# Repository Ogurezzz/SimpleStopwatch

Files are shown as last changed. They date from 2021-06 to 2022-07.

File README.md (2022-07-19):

# SimpleStopwatch
SimpleStopwatch_Fr
This is very simple stopwatch. I needed something that will count time when switch is On and reset when switch is off.
I found several solutions, but most of them are hardware worktime/switchOn counter. And you need to do some workaround to reset counter.

This SimpleStopwatch will solve my problem. It can count up to 99 hours. Uses up to 6 7-segment digits.

ToDo: 
1) (DONE) Make PCB with Atmega328, quartz, ULN2003 and indicators. With remote button/switch connection.
2) (DONE)Make 3D printed and CNC milled case for this Stopwatch. It should give me option for mounting to the panel of any device.
SimpleStopwatch_Bk

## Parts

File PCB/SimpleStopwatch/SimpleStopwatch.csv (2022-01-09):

Source: | /home/ogurezzz/Documents/Coding/GithubProjects/SimpleStopwatch/PCB/SimpleStopwatch/SimpleStopwatch.sch
Date: | Пн 02 авг 2021 20:10:25
Tool: | Eeschema 5.1.5+dfsg1-2build2
Generator: | /usr/share/kicad/plugins/bom_csv_grouped_by_value.py
Component Count: | 36
Individual Components:
Item | Qty | Reference(s) | Value | LibPart | Footprint | Datasheet | Price
 |  | C1 | 22u | Device:C_Small | Capacitor_SMD:C_1210_3225Metric_Pad1.42x2.65mm_HandSolder | https://www.chipdip.ru/product/grm32er61c226k | 23
 |  | C2 | 0.1u | Device:C_Small | Capacitor_SMD:C_0603_1608Metric_Pad1.05x0.95mm_HandSolder | https://www.chipdip.ru/product/grm188r71h104k | 10
 |  | C3 | 0.1u | Device:C_Small | Capacitor_SMD:C_0603_1608Metric_Pad1.05x0.95mm_HandSolder | https://www.chipdip.ru/product/grm188r71h104k | 10
 |  | C4 | 22p | Device:C_Small | Capacitor_SMD:C_0603_1608Metric_Pad1.05x0.95mm_HandSolder | https://www.chipdip.ru/product/grm1885c1h220j | 6
 |  | C5 | 22p | Device:C_Small | Capacitor_SMD:C_0603_1608Metric_Pad1.05x0.95mm_HandSolder | https://www.chipdip.ru/product/grm1885c1h220j | 6
 |  | C6 | 0.1u | Device:C_Small | Capacitor_SMD:C_0603_1608Metric_Pad1.05x0.95mm_HandSolder | https://www.chipdip.ru/product/grm188r71h104k | 10
 |  | C7 | 22u | Device:C_Small | Capacitor_SMD:C_1210_3225Metric_Pad1.42x2.65mm_HandSolder | https://www.chipdip.ru/product/grm32er61c226k | 23
 |  | C8 | 22u | Device:C_Small | Capacitor_SMD:C_1210_3225Metric_Pad1.42x2.65mm_HandSolder | https://www.chipdip.ru/product/grm32er61c226k | 23
 |  | C9 | 100uF | Device:CP_Small | Capacitor_SMD:CP_Elec_8x10.5 | https://www.chipdip.ru/product0/535002535 | 9
 |  | D1 | B120-E3 | Diode:B120-E3 | Diode_SMD:D_SMA_Handsoldering | https://www.chipdip.ru/product/b340a-e3-61t-2 | 15
 |  | H1 | RESET | Mechanical:MountingHole_Pad | TestPoint:TestPoint_Pad_D1.0mm | Печатная плата | 200
 |  | H2 | MOSI | Mechanical:MountingHole_Pad | TestPoint:TestPoint_Pad_D1.0mm | ~ | 0
 |  | H3 | MISO | Mechanical:MountingHole_Pad | TestPoint:TestPoint_Pad_D1.0mm | ~ | 0
 |  | H4 | SCK | Mechanical:MountingHole_Pad | TestPoint:TestPoint_Pad_D1.0mm | ~ | 0
 |  | H5 | +5V | Mechanical:MountingHole_Pad | TestPoint:TestPoint_Pad_D1.0mm | ~ | 0
 |  | H6 | GND | Mechanical:MountingHole_Pad | TestPoint:TestPoint_Pad_D1.0mm | ~ | 0
 |  | J1 | Switch | Connector:Screw_Terminal_01x02 | TerminalBlock:TerminalBlock_bornier-2_P5.08mm | https://www.chipdip.ru/product/dg308-2.54-02p-14-00ah | 42
 |  | J2 | Power | Connector:Screw_Terminal_01x02 | TerminalBlock:TerminalBlock_bornier-2_P5.08mm | https://www.chipdip.ru/product/dg308-2.54-02p-14-00ah | 42
 |  | L1 | L_Small | Device:L_Small | !MyFootprints:Inductor_CD54_Sumida | https://www.chipdip.ru/product/lqh43mn150k | 21
 |  | LED1 | 7SEG_3DIG_CC_v2 | !MyElements:7SEG_3DIG_CC_v2 | !MyFootprints:LED_7SEG_3DIG_CC_0.56 | https://www.chipdip.ru/product/bc56-12ewa | 260
 |  | LED2 | 7SEG_3DIG_CC_v2 | !MyElements:7SEG_3DIG_CC_v2 | !MyFootprints:LED_7SEG_3DIG_CC_0.56 | https://www.chipdip.ru/product/bc56-12ewa | 260
 |  | R1 | R_Small | Device:R_Small | Resistor_SMD:R_0603_1608Metric_Pad1.05x0.95mm_HandSolder | https://www.chipdip.ru/product0/9000079736 | 2
 |  | R2 | 1k | Device:R_Small | Resistor_SMD:R_0603_1608Metric_Pad1.05x0.95mm_HandSolder | https://www.chipdip.ru/product0/9000079736 | 2
 |  | R3 | 1k | Device:R_Small | Resistor_SMD:R_0603_1608Metric_Pad1.05x0.95mm_HandSolder | https://www.chipdip.ru/product0/9000079736 | 2
 |  | R4 | 1k | Device:R_Small | Resistor_SMD:R_0603_1608Metric_Pad1.05x0.95mm_HandSolder | https://www.chipdip.ru/product0/9000079736 | 2
 |  | R5 | 1k | Device:R_Small | Resistor_SMD:R_0603_1608Metric_Pad1.05x0.95mm_HandSolder | https://www.chipdip.ru/product0/9000079736 | 2
 |  | R6 | 1k | Device:R_Small | Resistor_SMD:R_0603_1608Metric_Pad1.05x0.95mm_HandSolder | https://www.chipdip.ru/product0/9000079736 | 2
 |  | R7 | 1k | Device:R_Small | Resistor_SMD:R_0603_1608Metric_Pad1.05x0.95mm_HandSolder | https://www.chipdip.ru/product0/9000079736 | 2
 |  | R8 | 1k | Device:R_Small | Resistor_SMD:R_0603_1608Metric_Pad1.05x0.95mm_HandSolder | https://www.chipdip.ru/product0/9000079736 | 2
 |  | R9 | 1k | Device:R_Small | Resistor_SMD:R_0603_1608Metric_Pad1.05x0.95mm_HandSolder | https://www.chipdip.ru/product0/9000079736 | 2
 |  | R10 | 5.1k | Device:R_Small | Resistor_SMD:R_0603_1608Metric_Pad1.05x0.95mm_HandSolder | https://www.chipdip.ru/product0/9000079736 | 2
 |  | R11 | 1.8k | Device:R_Small | Resistor_SMD:R_0603_1608Metric_Pad1.05x0.95mm_HandSolder | https://www.chipdip.ru/product0/9000079736 | 2
 |  | U1 | TPS5430DDA | Regulator_Switching:TPS5430DDA | Package_SO:TI_SO-PowerPAD-8_ThermalVias | https://www.chipdip.ru/product/tps5430ddar?from=suggest_product | 160
 |  | U2 | ATmega328P-AU | MCU_Microchip_ATmega:ATmega328P-AU | Package_QFP:TQFP-32_7x7mm_P0.8mm | https://www.chipdip.ru/product/atmega88-20au?from=suggest_product | 300
 |  | U3 | ULN2003 | Transistor_Array:ULN2003 | Package_SO:SOIC-16_4.55x10.3mm_P1.27mm | https://www.chipdip.ru/product/uln2003ad | 30
 |  | Y1 | Crystal_Small | Device:Crystal_Small | Crystal:Crystal_SMD_5032-2Pin_5.0x3.2mm | https://www.chipdip.ru/product0/9000523954 | 55
Collated Components:
Item | Qty | Reference(s) | Value | LibPart | Footprint | Datasheet | Price
1 | 3 | C1, C7, C8 | 22u | Device:C_Small | Capacitor_SMD:C_1210_3225Metric_Pad1.42x2.65mm_HandSolder | https://www.chipdip.ru/product/grm32er61c226k | 23
2 | 3 | C2, C3, C6 | 0.1u | Device:C_Small | Capacitor_SMD:C_0603_1608Metric_Pad1.05x0.95mm_HandSolder | https://www.chipdip.ru/product/grm188r71h104k | 10
3 | 2 | C4, C5 | 22p | Device:C_Small | Capacitor_SMD:C_0603_1608Metric_Pad1.05x0.95mm_HandSolder | https://www.chipdip.ru/product/grm1885c1h220j | 6
4 | 1 | C9 | 100uF | Device:CP_Small | Capacitor_SMD:CP_Elec_8x10.5 | https://www.chipdip.ru/product0/535002535 | 9
5 | 1 | D1 | B120-E3 | Diode:B120-E3 | Diode_SMD:D_SMA_Handsoldering | https://www.chipdip.ru/product/b340a-e3-61t-2 | 15
6 | 1 | H1 | RESET | Mechanical:MountingHole_Pad | TestPoint:TestPoint_Pad_D1.0mm | Печатная плата | 200
7 | 1 | H2 | MOSI | Mechanical:MountingHole_Pad | TestPoint:TestPoint_Pad_D1.0mm | ~ | 0
8 | 1 | H3 | MISO | Mechanical:MountingHole_Pad | TestPoint:TestPoint_Pad_D1.0mm | ~ | 0
9 | 1 | H4 | SCK | Mechanical:MountingHole_Pad | TestPoint:TestPoint_Pad_D1.0mm | ~ | 0
10 | 1 | H5 | +5V | Mechanical:MountingHole_Pad | TestPoint:TestPoint_Pad_D1.0mm | ~ | 0
11 | 1 | H6 | GND | Mechanical:MountingHole_Pad | TestPoint:TestPoint_Pad_D1.0mm | ~ | 0
12 | 1 | J1 | Switch | Connector:Screw_Terminal_01x02 | TerminalBlock:TerminalBlock_bornier-2_P5.08mm | https://www.chipdip.ru/product/dg308-2.54-02p-14-00ah | 42
13 | 1 | J2 | Power | Connector:Screw_Terminal_01x02 | TerminalBlock:TerminalBlock_bornier-2_P5.08mm | https://www.chipdip.ru/product/dg308-2.54-02p-14-00ah | 42
14 | 1 | L1 | L_Small | Device:L_Small | !MyFootprints:Inductor_CD54_Sumida | https://www.chipdip.ru/product/lqh43mn150k | 21
15 | 2 | LED1, LED2 | 7SEG_3DIG_CC_v2 | !MyElements:7SEG_3DIG_CC_v2 | !MyFootprints:LED_7SEG_3DIG_CC_0.56 | https://www.chipdip.ru/product/bc56-12ewa | 260
16 | 1 | R1 | R_Small | Device:R_Small | Resistor_SMD:R_0603_1608Metric_Pad1.05x0.95mm_HandSolder | https://www.chipdip.ru/product0/9000079736 | 2
17 | 8 | R2, R3, R4, R5, R6, R7, R8, R9 | 1k | Device:R_Small | Resistor_SMD:R_0603_1608Metric_Pad1.05x0.95mm_HandSolder | https://www.chipdip.ru/product0/9000079736 | 2
18 | 1 | R10 | 5.1k | Device:R_Small | Resistor_SMD:R_0603_1608Metric_Pad1.05x0.95mm_HandSolder | https://www.chipdip.ru/product0/9000079736 | 2
19 | 1 | R11 | 1.8k | Device:R_Small | Resistor_SMD:R_0603_1608Metric_Pad1.05x0.95mm_HandSolder | https://www.chipdip.ru/product0/9000079736 | 2
20 | 1 | U1 | TPS5430DDA | Regulator_Switching:TPS5430DDA | Package_SO:TI_SO-PowerPAD-8_ThermalVias | https://www.chipdip.ru/product/tps5430ddar?from=suggest_product | 160
21 | 1 | U2 | ATmega328P-AU | MCU_Microchip_ATmega:ATmega328P-AU | Package_QFP:TQFP-32_7x7mm_P0.8mm | https://www.chipdip.ru/product/atmega88-20au?from=suggest_product | 300
22 | 1 | U3 | ULN2003 | Transistor_Array:ULN2003 | Package_SO:SOIC-16_4.55x10.3mm_P1.27mm | https://www.chipdip.ru/product/uln2003ad | 30
23 | 1 | Y1 | Crystal_Small | Device:Crystal_Small | Crystal:Crystal_SMD_5032-2Pin_5.0x3.2mm | https://www.chipdip.ru/product0/9000523954 | 55

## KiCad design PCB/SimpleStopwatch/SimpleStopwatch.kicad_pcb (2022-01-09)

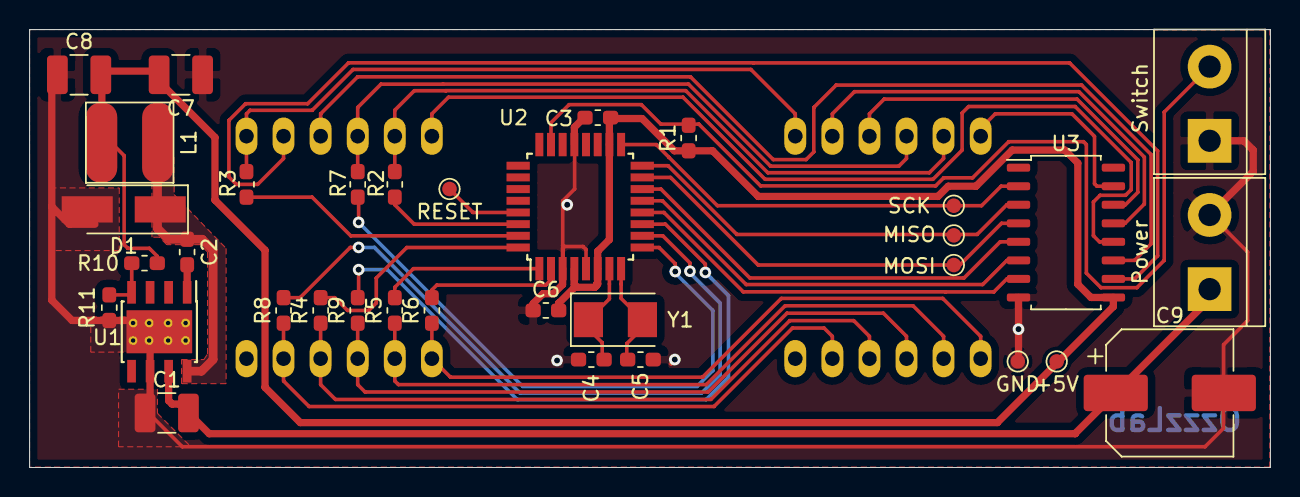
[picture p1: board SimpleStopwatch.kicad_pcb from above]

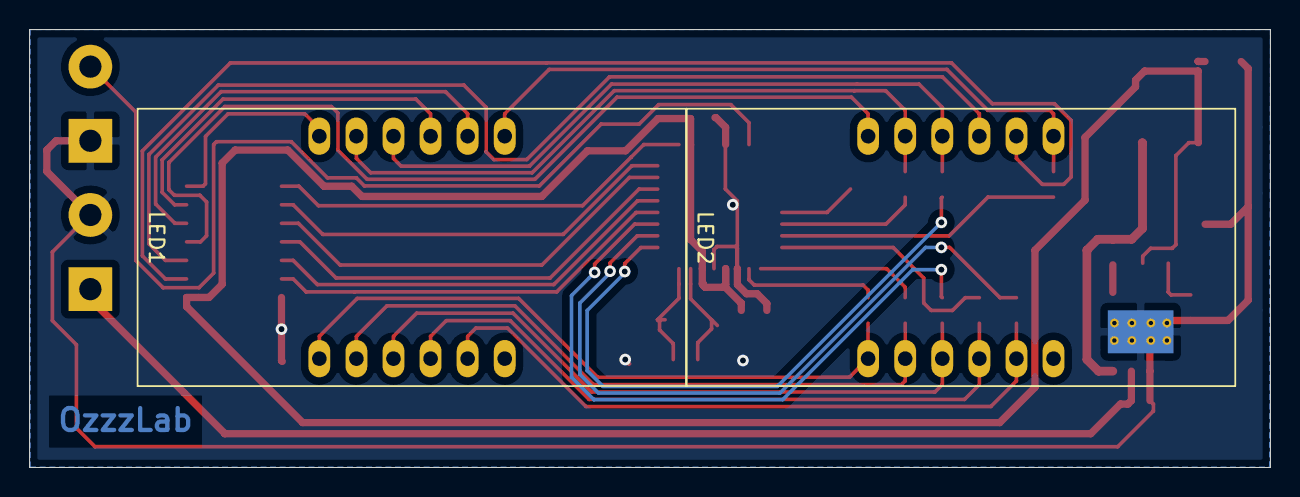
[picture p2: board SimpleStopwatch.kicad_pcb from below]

Board: 2 copper layers, 85.0 x 30.0 mm, 36 parts (2 on the bottom side), 38 nets.

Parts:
C1, C7, C8: 22u; C_1210_3225Metric_Pad1.42x2.65mm_HandSolder
C2, C3, C6: 0.1u; C_0603_1608Metric_Pad1.05x0.95mm_HandSolder
C4, C5: 22p; C_0603_1608Metric_Pad1.05x0.95mm_HandSolder
C9: 100uF; CP_Elec_8x10.5
D1: B120-E3; D_SMA_Handsoldering
H1: RESET; TestPoint_Pad_D1.0mm
H2: MOSI; TestPoint_Pad_D1.0mm
H3: MISO; TestPoint_Pad_D1.0mm
H4: SCK; TestPoint_Pad_D1.0mm
H5: +5V; TestPoint_Pad_D1.0mm
H6: GND; TestPoint_Pad_D1.0mm
J1: Switch; TerminalBlock_bornier-2_P5.08mm
J2: Power; TerminalBlock_bornier-2_P5.08mm
L1: L_Small; Inductor_CD54_Sumida
LED1, LED2: 7SEG_3DIG_CC_v2; LED_7SEG_3DIG_CC_0.56
R1: R_Small; R_0603_1608Metric_Pad1.05x0.95mm_HandSolder
R2, R3, R4, R5, R6, R7, R8, R9: 1k; R_0603_1608Metric_Pad1.05x0.95mm_HandSolder
R10: 5.1k; R_0603_1608Metric_Pad1.05x0.95mm_HandSolder
R11: 1.8k; R_0603_1608Metric_Pad1.05x0.95mm_HandSolder
U1: TPS5430DDA; TI_SO-PowerPAD-8_ThermalVias
U2: ATmega328P-AU; TQFP-32_7x7mm_P0.8mm
U3: ULN2003; SOIC-16_4.55x10.3mm_P1.27mm
Y1: Crystal_Small; Crystal_SMD_5032-2Pin_5.0x3.2mm

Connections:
+5V: C3.1, C6.2, C7.2, C8.2, H5.1, L1.2, R1.1, R10.2, U2.4, U2.6, U2.18, U3.9
+24V: C1.2, C9.1, J2.1, U1.7
Dig1: U2.12, U3.7
Dig2: U2.13, U3.6
Dig3: U2.14, U3.5
Dig4: H2.1, U2.15, U3.4
Dig5: H3.1, U2.16, U3.3
Dig6: H4.1, U2.17, U3.2
GND: C1.1, C3.2, C4.1, C5.2, C6.1, C7.1, C8.1, C9.2, D1.2, H6.1, J1.1, J2.2, R11.1, U1.6, U1.9, U2.3, U2.5, U2.21, U3.8
unnamed: C2.1, D1.1, L1.1, U1.8
unnamed: C2.2, U1.1
unnamed: C4.2, U2.7, Y1.1
unnamed: C5.1, U2.8, Y1.2
unnamed: H1.1, U2.29
unnamed: LED1.DIG1, U3.15
unnamed: LED1.DIG2, U3.14
unnamed: LED1.DIG3, U3.13
unnamed: LED2.DIG1, U3.12
unnamed: LED2.DIG2, U3.11
unnamed: LED2.DIG3, U3.10
unnamed: R2.2, U2.30
unnamed: R3.2, U2.31
unnamed: R4.2, U2.32
unnamed: R5.2, U2.1
unnamed: R6.2, U2.2
unnamed: R7.2, U2.9
unnamed: R8.2, U2.10
unnamed: R9.2, U2.11
unnamed: R10.1, R11.2, U1.4
SW: J1.2, R1.2, U2.23
SegA: LED1.A, LED2.A, R2.1
SegB: LED1.B, LED2.B, R3.1
SegC: LED1.C, LED2.C, R4.1
SegD: LED1.D, LED2.D, R5.1
SegE: LED1.E, LED2.E, R6.1
SegF: LED1.F, LED2.F, R7.1
SegG: LED1.G, LED2.G, R8.1
SegP: LED1.DP, LED2.DP, R9.1

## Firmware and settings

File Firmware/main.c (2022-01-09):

/*
 * main.c
 *
 * Created: 18.05.2021 16:30:00
 * Author : Ogurezzz
 */ 
#include <avr/signature.h>
#include <avr/io.h>
#include <avr/interrupt.h>
#include <util/delay.h>
#include "shiftLED.h"

volatile uint32_t secondsPassed = 0;

#define BTN_DDR						DDRC
#define BTN_PORT					PORTC
#define BTN_RESET 					PORTC0

#define TIMER_START 				TCCR1B |= _BV(CS12) 						// Включаем таймер с предделителем 256 
#define TIMER_STOP 					TCCR1B &= ~(_BV(CS12)|_BV(CS10));TCNT1 = 0  // Останавливаем и сбрасываем таймер

ISR(TIMER1_COMPA_vect) 							// Прерывание. 1 раз в секунду.
{
	secondsPassed++;
	if (secondsPassed>=360000) secondsPassed=0;
	setTimeToPrint(secondsPassed);
}

ISR(TIMER2_COMPA_vect) 							// Прерывание. 1 раз в мс. Отрисовка 1 символа за вызов
{
	printDigit();
}

ISR(PCINT1_vect){								// Прерывание по изменению пинов PCINT14..8
	if (bit_is_clear(PINC, BTN_RESET))
	{
		TIMER_STOP;
		secondsPassed = 0;
		setTimeToPrint(secondsPassed);
	}else{
		TIMER_START;
	}
}

int main(void)
{
	asm volatile("cli"); 						// Выключаем прерывания
	initShiftLED();								// Настройка семисегментных индикаторов
	/*DIGIT_PORT=0xff;
	LED_PORT=0xff;
	_delay_ms(1000);*/

	// Настройка кнопок
	PCICR |= _BV(PCIE1); 						// Включаем прерывания по любому изменению на портах PCINT14..8. Нам нужна кнопка на 8м порту.
	PCMSK1 |= _BV(BTN_RESET); 					// Реагируем только на кнопку, подключенную к PCINT8+PCINT9;
	BTN_DDR &= ~(_BV(BTN_RESET)); 				// Настраиваем пин кнопоки на вход.
	BTN_PORT |= _BV(BTN_RESET); 				// Включаем подтяжку на пинах для кнопок

// Настраиваем таймер часов (1с)
TCCR1B = _BV(WGM12);		// Сброс по достижению заданног значения в OCR1A. Предделитель 256.
TIMER_START;
OCR1A = 31250;				// Значение для нормального кварца 8MHz
TCNT1 = 0;					// Установить начальное значение счётчиков
TIMSK1 |= _BV(OCIE1A);		// Разрешаем прерывание По совпадению с OCR1A

	// Настраиваем таймер тиков (1мс)
	TCCR2A = 0;
	TCCR2A = _BV(WGM21);						// Установить режим Compare Match
	TCCR2B = _BV(CS22);							// Предделитель 64
	OCR2A = 125; 								// Установить значение в регистр сравнения
	TCNT2 = 0;									// Установить начальное значение счётчиков
	TIMSK2 |= _BV(OCIE2A);						// Разрешаем прерывание По совпадению с OCR2A
	
	asm volatile("sei");						// Включаем прерывания

	while (1) {}
}

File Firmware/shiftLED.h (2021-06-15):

#ifndef SHIFTLED_H
#define SHIFTLED_H

#include <avr/io.h>
#include <avr/pgmspace.h>

//#define SOFTWARE_SPI
#define DIRECT_CONNECTION_PORTD


#ifdef SOFTWARE_SPI
    #define LED_DDR         DDRC
    #define LED_PORT        PORTC
    #define LED_DAT_PIN     PORTC0
    #define LED_CLK_PIN     PORTC1
    #define LED_LAT_PIN     PORTC2

    #define SEND_CLOCK  LED_PORT |= _BV(LED_CLK_PIN);LED_PORT &= ~_BV(LED_CLK_PIN)
    #define SEND_LATCH  LED_PORT |= _BV(LED_LAT_PIN);LED_PORT &= ~_BV(LED_LAT_PIN)
    #define SEND_DAT_1  LED_PORT |= _BV(LED_DAT_PIN)
    #define SEND_DAT_0  LED_PORT &= ~_BV(LED_DAT_PIN)
#endif

#ifdef DIRECT_CONNECTION_PORTD
    #define LED_DDR         DDRD
    #define LED_PORT        PORTD

	#define DIGIT_DDR		DDRB
	#define DIGIT_PORT		PORTB

#endif




#define DIGITS_NUM    6           						// Количество сегментов

void initShiftLED(void);								// Инициализация перефирии для работы
void printDigit(void);									// Вывод одного числа. Для динамической индикации.

void setTimeToPrint(uint32_t seconds);					// Вывести время в часах, минутах и секундах. С разделением точкой
void setFloatToPrint(float number, uint8_t dotMask);	// Вывести число с плавающей точкой, точка будет стоять в заданной позиции.
void setIntToPrint(int32_t number);						// Вывести целое число.

void dispPrintFloat(float number);						// ToDo: Убрать
void moveDot(float number);								// ToDo: Переработать.

#endif

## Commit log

2021-06-10 Added KiCAD PCB
    [SimpleStopwatch.kicad_pcb, SimpleStopwatch.sch]
2021-06-10 Changed to correct 8MHz quartz
    [main.c]
2021-06-11 Removed ULN2003 Mistake
    [SimpleStopwatch.kicad_pcb, SimpleStopwatch.sch]
2021-06-11 Changed LDO to DCDC module board
    [SimpleStopwatch.kicad_pcb, SimpleStopwatch.sch]
2021-06-11 Mini360 little changes
    [SimpleStopwatch.sch]
2021-06-11 PCB Release v0.2
2021-06-11 Some PCB improvements
    [SimpleStopwatch.kicad_pcb]
2021-06-15 PCB with Mini360 module
2021-06-15 PCB updates
    [SimpleStopwatch.sch]
2021-06-15 Added TPS5430 DCDC. Yuri version
    [SimpleStopwatch.kicad_pcb, SimpleStopwatch.sch]
2021-06-15 PCB Pictures
2021-06-15 Changed 3D model for 7-seg indicator
    [SimpleStopwatch.kicad_pcb]
2021-06-29 PCB Improvements. C0603 to C1210
2021-06-29 PCB Changes. Size of capacitors
    [SimpleStopwatch.kicad_pcb, SimpleStopwatch.sch]
2022-07-19 Update .gitignore, main.c, and 22 more files...
    [SimpleStopwatch.csv, SimpleStopwatch.kicad_pcb, SimpleStopwatch.sch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]
